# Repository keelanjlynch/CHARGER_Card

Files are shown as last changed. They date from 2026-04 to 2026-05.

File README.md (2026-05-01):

# CHARGER Card

## A compact, interactable business card created for The Univeristy of Alabama in Huntsville Electrical and Computer Engineering Department.

This project was created by Aadam Saafi, Austin Nash, John D'Alessandro, and Keelan Lynch. It utilizes a TFT LCD display, capacative touch buttons, USB interface for flashing/power, and an ESP32-S3-WROOM1.
The code for the project was written in Arduino IDE and the PCB design/layout was created using KiCad. Some of the features of the board in its current state include:

* Three educational activities relating to ECE disciplines included below:
* A Cyber Security activity of brute force byte decryption (similar to mastermind or wordle)
* An Electrical Engineering connect-the-dots activity where user connect electrical components to create an electrical connection
* A Computer Engineering activity where user adjusts inputs and logic gates to get the desired output
* Capacative touch calibration
* Menu selection
* Bitmap rendering

Some additions that could be made using the capabilities of the ESP32-S3:
* Bluetooth utilization
* Wi-Fi utilization
* Artifical Intelligence
* Additional games
* Resume display
* Web browser
* Animated display
* Etc.

## Demo Videos

https://www.youtube.com/watch?v=7o9A-FuoEWo

## How to install this project

1. Clone this project
2. Install Arduino IDE - https://www.arduino.cc/en/software/
3. Install KiCad - https://www.kicad.org/download/

## Opening this project in KiCad (we recommend using V2 of the design)

1. Open Buisness_Card_PCB.kicad_pro in KiCad

## Opening this project in Ardunio

1. Open ChargerCardSoftware.ino in Arduino IDE
2. In Board Manager, install esp32 by Espressif Systems
3. In Library Manager, install "Adafruit GFX Library" and "Adafruit ST7735 and ST7789 Library"
4. Ensure that the CHARGER Card is plugged into your computer via USB
5. From the top menu: Tools > Board: > esp32 > ESP32S3 Dev Module
6. Select the port that the board is currently connected to
7. Once set up, you can upload any changes made in code
8. If this is your first time connecting the board: Hold down the boot switch (lower push button), press and release the reset switch (upper push button), release boot switch. This will put the board into boot mode.

# Altering the code

It will be easiest if you edit this code within an installed verion of the Arduino IDE. The ChargerCardSoftware.ino file is where all code for the project currently resides. 
The bitmaps.h file has all the bitmaps used by the primary ino file. The code is seperate into the following sections: framework drawing functions, cyber activity, ee activity, cpe activity, and framework functions. Global variables can be found at the top of each section (i.e globals used by the cyber activity are found at the top of the cyber activity section).

The setup() and loop() functions are the core of any Arduino code and are located at the very bottom of ChargerCardSoftware.ino. Additional functions and their descriptions are listed below:

* calibrateTouch() - called in setup, establishes a baseline for the capacative touch inputs
* updateTouchReadings() - called in loop to get a current reading from the touch inputs
* touchTest(int i) - compares the given touch point i with the established baseline
* displayLogo() - called to display full sized UAH logo
* drawGithub() - displays bitmap of QR code to this github
* drawFaculty(int f) - called to display image and description for the given UAH ECE faculty member f
* drawMenuSelect() - draws/updates the left side of main menu when the cursor is moved
* drawBonusMenuSelect() - draws/updates the left side of bonus menu when the cursor is moved
* drawMainMenu() - draws main menu
* drawBonusMenu() - draws bonus menu
* drawAboutPage() - draws about page
* returnMainMenu() - used to make main menu our current scene
* moveSelectionLeft() and moveSelectionRight() - used by the CS and EE activity to update the cursor left or right
* toggleSelectedBit() - used by CS activity to toggle the bit highlighted by the cursor
* submitGuess() - used by CS activity when the user presses A
* drawUI() - used by CS activity to draw graphical user interface
* drawTopBar() - component of the CS activity gui
* drawCurrentGuess() - component of the CS activity gui
* drawPreviousGuesses() - component of the CS activity gui
* drawHintBar() - component of the CS activity gui
* drawStats() - component of the CS activity gui
* drawKeyboard() - component of the CS activity gui
* uint8_t countCorrectBits(uint8_t guess, uint8_t target) - CS activity function for counting how many bits are correct
* showVictory() - CS activity function to draw victory message
* showDefeat() - CS activity function to draw game over message
* String getBinaryString(uint8_t num) - string conversion in CS activity
* String getHexString(uint8_t num) - string conversion in CS activity
* newCyberGame() - called when CS activity begins or is reset
* selectCurrentNode() - EE activity function called when user presses A
* initLevel(int level) - EE activity function for level initialization
* setupLevelX() - X is a number, EE activity functions used to initialize each level
* handleNodeTouch(int nodeId) - EE activity function that handles logic for touch on current node
* checkCircuitComplete() - EE activity function that checks if circuit is complete
* drawConnection(int node1, int node2, uint16_t color, int offset) - EE activity function to draw wire connections
* drawComponentSymbol(int x, int y, ComponentType type, bool active) - EE activity function for drawing components
* drawCircuit() - top level EE activity function called when drawing the circuit
* drawNodeLabel(int nodeIndex, uint16_t textColor) - EE activity function that draws a label for each component
* drawControls() - EE activity GUI showing controls
* showError(const char* message) - EE activity error message
* showSuccess() - EE activity level win message
* showGameComplete() - congratulations message shown at the end of EE activity
* resetLevel() - EE activity function to reset current level
* checkVal(int i) - CPE activity recursive function used to test logical output from edited diagram
* drawCursor() - CPE activity function used to draw updated cursor position
* drawWire(int x0, int y0, int i) - CPE activity function to draw wire between current node pos (x0, y0) and other node i
* drawLogic(int i) - CPE activity function to draw/update an input component
* drawNot(int i) - CPE activity function to draw NOT gate
* drawAnd(int i) - CPE activity function to draw AND gate
* drawOr(int i) - CPE activity function to draw OR gate
* drawSwitch(int i) - CPE activity function to draw/update a switch
* drawLED(int i) - CPE activity function to draw output component
* drawComponent(int i) - top level CPE activity function for drawing logic components
* drawWin() - CPE activity function to draw level complete message
* drawCPELevel() - CPE activity function to draw current level
* componentInteract(int i) - CPE activity function that handles if user presses A on component
* startCPELevel(int l) - initializes current CPE level l
* updateCPE() - CPE activity function to refresh screen when an edit was made
* startCPE() - called to begin the CPE activity
* cpeInputHandling(int t) - CPE activity function to handle all acceptable touch button inputs
* enterScene(int s) - used in main menu to switch scene and initialize new scene
* enterBonusScene(int s) - used in main menu to enter bonus menu
* update_mm(int d) - update main menu
* update_bm(int d) - update bonus menu
* update_faculty(int f) - update faculty page
* update_about(int a) - update about page

## Adding Custom Bitmaps

Custom bitmaps can be created from any image and drawn very easily using the Adafruit GFX library. The steps for converting and displaying the image of your choice will be listed below:

1. download your desired image (.png or .jpeg would be best)
2. go to https://javl.github.io/image2cpp/
3. select your file
4. alter canvas size (max size is 320x170 for this device)
5. scale to fit or scale to fill
6. adjust brightness/alpha threshold to get your desired image
7. ensure that code output format is set to Arduino Code, single bitmap
8. change the name of the array to something simple
9. copy and paste array into bitmaps.h file
10. tft.drawBitmap([x_pos],[y_pos],[array name],[width],[height],[color])

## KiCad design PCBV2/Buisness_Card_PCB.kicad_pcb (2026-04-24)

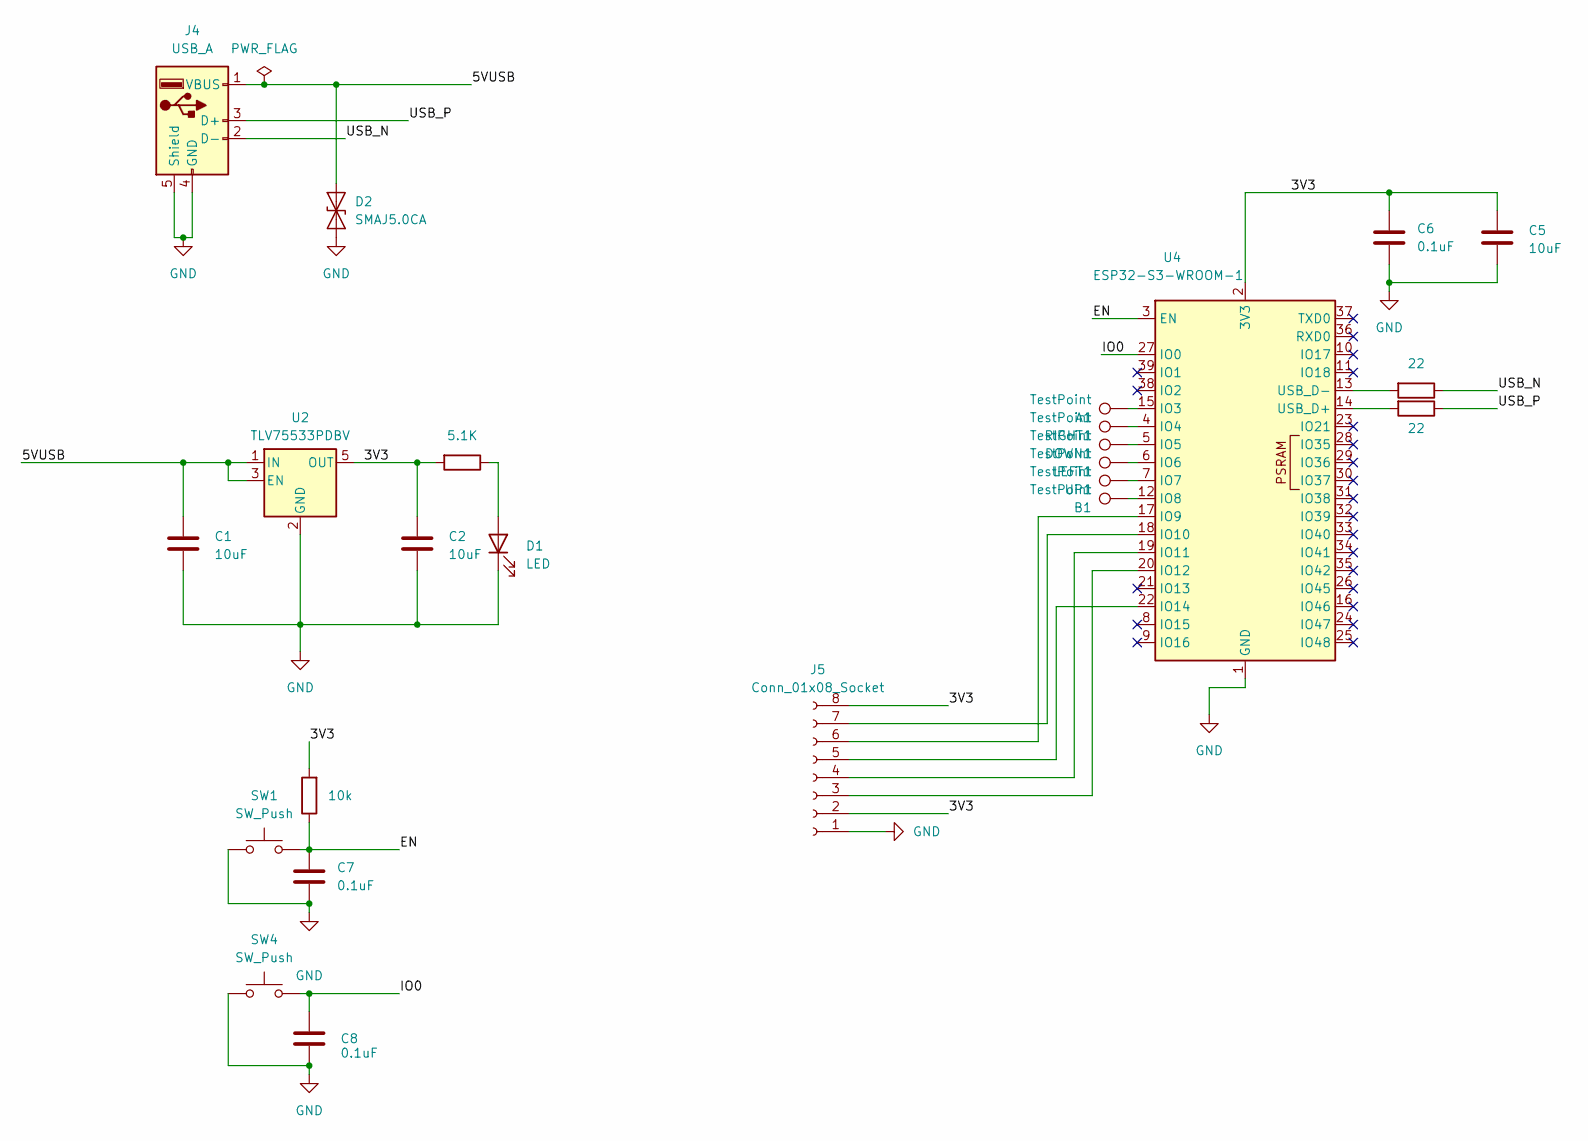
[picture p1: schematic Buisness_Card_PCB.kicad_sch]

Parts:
A1: TestPoint; TouchPad_8mm
B1: TestPoint; TouchPad_8mm
C1, C2, C5: 10uF; C_0201_0603Metric
C6, C7, C8: 0.1uF; C_0201_0603Metric
D1: LED; LED_0201_0603Metric
D2: SMAJ5.0CA; D_SMA
DOWN1: TestPoint; TouchPad_8mm
J4: USB_A; USB_A_PCB_Edge_receptacle
J5: Conn_01x08_Socket; PinHeader_1x08_P2.54mm_Vertical
LEFT1: TestPoint; TouchPad_8mm
R3: 5.1K; R_0201_0603Metric
R4, R6: 22; R_0201_0603Metric
R5: 10k; R_0201_0603Metric
RIGHT1: TestPoint; TouchPad_8mm
SW1, SW4: SW_Push; SW_SPST_TL3305A
U2: TLV75533PDBV; SOT-23-5
U4: ESP32-S3-WROOM-1
UP1: TestPoint; TouchPad_8mm

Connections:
/3V3: C2.2, C5.2, C6.2, J5.2, J5.8, R3.2, R5.2, U2.5 (OUT), U4.2 (3V3)
/5VUSB: C1.2, D2.2 (A2), J4.1 (VBUS), U2.1 (IN), U2.3 (EN)
/EN: C7.2, R5.1, SW1.2, U4.3 (EN)
/IO0: C8.2, SW4.2, U4.27 (IO0)
/USB_N: J4.2 (D-), R4.1
/USB_P: J4.3 (D+), R6.1
GND: C1.1, C2.1, C5.1, C6.1, C7.1, C8.1, D1.1 (K), D2.1 (A1), J4.4 (GND), J4.5 (Shield), J5.1, SW1.1, SW4.1, U2.2 (GND), U4.1 (GND), U4.40 (GND), U4.41 (GND)
unnamed: D1.2 (A), R3.1
unnamed: J5.3, U4.20 (IO12)
unnamed: J5.4, U4.19 (IO11)
unnamed: J5.5, U4.22 (IO14)
unnamed: J5.6, U4.17 (IO9)
unnamed: J5.7, U4.18 (IO10)
unnamed: A1.1, U4.15 (IO3)
unnamed: RIGHT1.1, U4.4 (IO4)
unnamed: DOWN1.1, U4.5 (IO5)
unnamed: LEFT1.1, U4.6 (IO6)
unnamed: U4.7 (IO7), UP1.1
unnamed: B1.1, U4.12 (IO8)
unnamed: R6.2, U4.14 (USB_D+)
unnamed: R4.2, U4.13 (USB_D-)

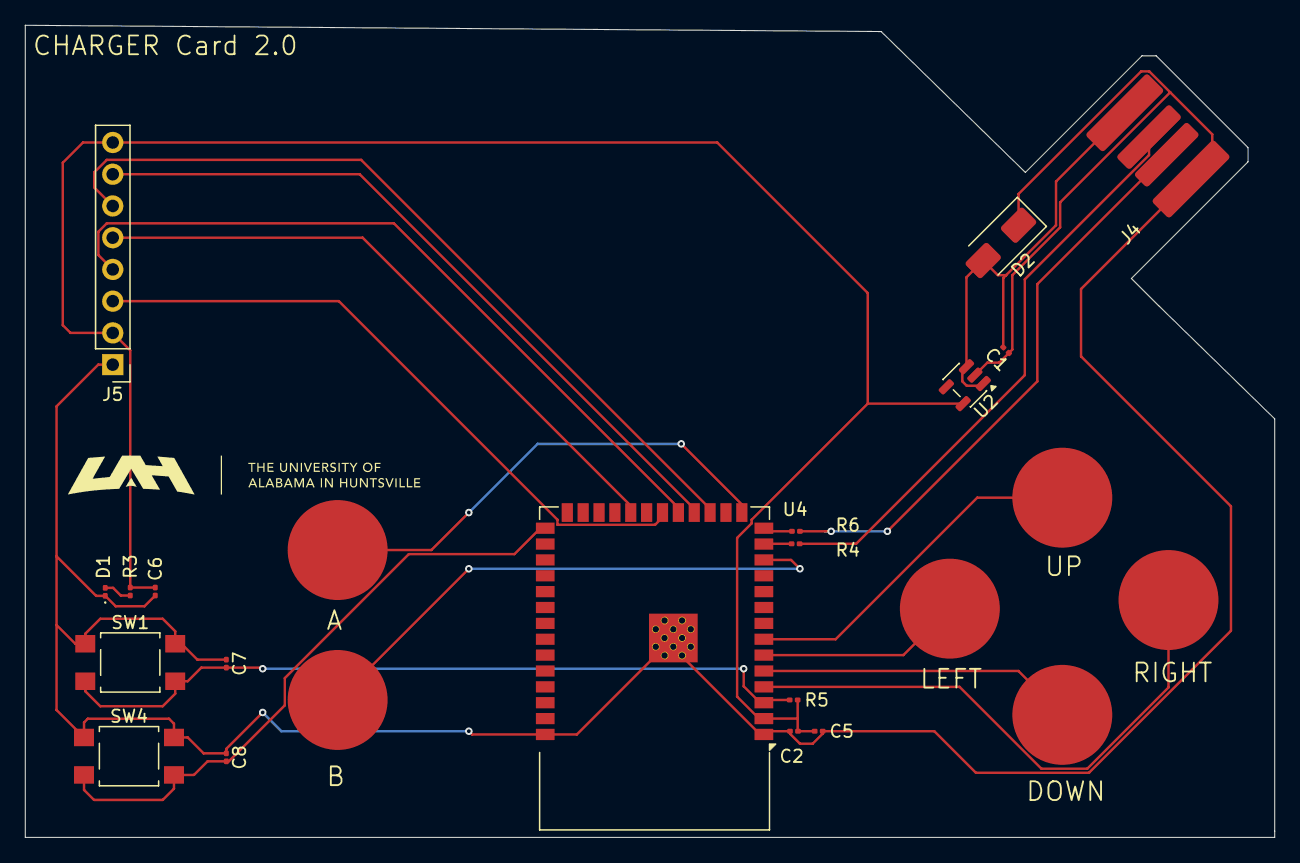
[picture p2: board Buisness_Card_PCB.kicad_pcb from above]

Board: 2 copper layers, 100.0 x 65.0 mm, 24 parts (0 on the bottom side), 21 nets.

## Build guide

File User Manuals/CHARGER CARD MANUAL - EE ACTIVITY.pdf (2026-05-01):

CHARGER CARD MANUAL - EE ACTIVITY

CONTROLS:
- LEFT/RIGHT to move between nodes
- A to select node as next connection
- DOWN to undo
- UP for hint
- B to return to main menu

GAMEPLAY:
- User must connect nodes together to create an electrical connection
- User starts at node S (for start) and ends at node EE (for end)
- Proper connections will show up as a green wire
- Improper connections will result in an error message followed by level reset

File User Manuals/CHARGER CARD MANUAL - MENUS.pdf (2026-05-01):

CHARGER CARD MANUAL - MENUS

CONTROLS:
- UP/DOWN to move between menu options
- A to select a menu option and switch scenes

MENU OPTIONS:
- How To
- Cyber Challenge
- EE Circuit Connect
- CPE Logic Puzzle
- Bonus
- About

LIST OF SCENES

How To:
- Empty at the moment

Cyber Challenge:
- The cyber security activity

EE Circuit Connect:
- The electrical engineering activity

CPE Logic Puzzle:
- The computer engineering activity

Bonus:
- The bonus menu
- The bonus menu has the following options:
- ECE Faculty
- Github
- Return

About:
- The about page
- Displays information about the project
- UP/DOWN to scroll up and down the about page
- B to return to main menu

ECE Faculty:
- The faculty page
- Displays images and descriptions of ECE faculty members
- LEFT/RIGHT to move through ECE faculty members

- B to return to main menu

Github:
- Displays QR code link to project github
- B to return to main menu

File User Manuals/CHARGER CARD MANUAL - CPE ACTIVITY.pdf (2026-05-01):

CHARGER CARD MANUAL - CPE ACTIVITY

CONTROLS:
- UP/DOWN/LEFT/RIGHT to move the cursor (drawn as a square) anywhere on screen
- A to toggle component that the cursor is on (only inputs and switches are interactable)
- B to return to main menu

GAMEPLAY:
- The goal of the player is to get the output to be logical high.
- The player can achieve this by altering input(s) until the proper output is achieved.
- In between the input(s) and the output will be logic gates.
- The player must understand or learn how these gates operate to know which inputs will create the correct output.

LOGIC GATES:

- NOT GATE:
- 1 input
- 1 output
- Outputs the NOT of the input
- Symbol:
- Truth Table:
Input | Output
1 | 0
0 | 1
- AND GATE:
- 2 inputs
- 1 output
- Outputs the AND of the two inputs
- Symbol:

- Truth Table:
Input 1 | Input 2 | Outpu t
0 | 0 | 0
0 | 1 | 0
1 | 0 | 0
1 | 1 | 1
- OR GATE:
- 2 inputs
- 1 output
- Outputs the OR of the two inputs
- Symbal:
- Truth Table:
Input 1 | Input 2 | Outpu t
0 | 0 | 0
0 | 1 | 1
1 | 0 | 1
1 | 1 | 1
- SWITCH:
- 1 input
- 1 output
- If open, output is 0
- If closed, output is the input value
- Can be toggled open or closed by the user
- Symbal:
- INPUT:
- 1 output

- Output is the current value of this component
- Can be toggled high or low by the user
- Symbol is either the character 1 or 0
- OUTPUT:
- 1 input
- Displayed as a large circle
- If input is high, will change to a filled green circle

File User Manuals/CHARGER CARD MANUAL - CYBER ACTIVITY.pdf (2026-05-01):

CHARGER CARD MANUAL - CYBER ACTIVITY

CONTROLS:
- LEFT/RIGHT to move between bits
- UP/DOWN to toggle bit
- A to submit attempt
- B to return to main menu

GAMEPLAY:
- User must brute force an 8 bit encrypted message
- User makes their guess by toggling bits and then submitting their attempt
- The section called “Guesses” displays previous guesses and how many bits out of 8 you had correct
- The user has five tries to submit the proper encrypted byte
- If user is unsuccessful, the game displays “ACCESS DENIED” and the game resets with a new encryption
- If user is successful, the game displays “ACCESS GRANTED” and the user can try a new encryption

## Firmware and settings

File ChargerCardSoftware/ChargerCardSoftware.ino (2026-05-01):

#include <Adafruit_GFX.h>
#include <Adafruit_ST7789.h>
#include <SPI.h>

#include "bitmaps.h"

#define TFT_CS    10
#define TFT_DC     9
#define TFT_RST   14
#define TFT_SCLK  12
#define TFT_MOSI  11

SPIClass mySPI(FSPI);
Adafruit_ST7789 tft = Adafruit_ST7789(&mySPI, TFT_CS, TFT_DC, TFT_RST);

// Touch pins
#define PIN_A      3
#define PIN_B      8
#define PIN_UP     7
#define PIN_DOWN   5
#define PIN_LEFT   6
#define PIN_RIGHT  4

struct TouchButton {
  const char* label;
  int pin;
  int baseline;
  int raw;
  int diff;
  int threshold;
};

TouchButton buttons[] = {
  {"A",     PIN_A,     0, 0, 0, 18},
  {"B",     PIN_B,     0, 0, 0, 18},
  {"UP",    PIN_UP,    0, 0, 0, 18},
  {"DOWN",  PIN_DOWN,  0, 0, 0, 18},
  {"LEFT",  PIN_LEFT,  0, 0, 0, 18},
  {"RIGHT", PIN_RIGHT, 0, 0, 0, 18},
};

const int NUM_BUTTONS = sizeof(buttons) / sizeof(buttons[0]);
int main_selection = 0; //for current cursor position in main menu
int bonus_selection = 0; //for current cursor position in bonus menu
const int BONUS_MAX = 2; //change this constant if you add more options for the bonus menu
int faculty = 0; //numbered 0-20 for all ECE faculty
int scene = 0; //keeps track of current "scene"
              //0 for main menu
              //1 for How To
              //2 for Cyber
              //3 for EE
              //4 for CPE
              //5 for Bonus
              //6 for About
              //7 for ECE Faculty page
              //8 for QR code page

void calibrateTouch() {
  for (int i = 0; i < NUM_BUTTONS; i++) {
    long sum = 0;
    for (int j = 0; j < 40; j++) {
      sum += touchRead(buttons[i].pin);
      delay(10);
    }
    buttons[i].baseline = sum / 40;
  }
}

void updateTouchReadings() {
  for (int i = 0; i < NUM_BUTTONS; i++) {
    buttons[i].raw = touchRead(buttons[i].pin);
    buttons[i].diff = buttons[i].baseline - buttons[i].raw;

    if (buttons[i].diff < 0) {
      buttons[i].diff = 0;
    }
  }
}

bool touchTest(int i) {
  return buttons[i].diff < buttons[i].threshold;
}

void displayLogo() {
  tft.drawBitmap(0,0,uah_logo,320,170,ST77XX_WHITE);
}

void drawGithub() {
  tft.fillScreen(ST77XX_BLACK);
  tft.drawBitmap(85,10,github,150,150,ST77XX_WHITE);
}

void drawFaculty(int f) {
  tft.fillScreen(ST77XX_BLACK);
  tft.setTextColor(ST77XX_WHITE, ST77XX_BLACK);
  __uint16_t faceColor = ST77XX_WHITE;
  switch(f) {
    case 0: //Dr. Beal
      tft.drawBitmap(60,0,beal,320,170,faceColor);
      tft.fillRect(0,0,150,170,ST77XX_BLACK);
      tft.setTextSize(2);
      tft.setCursor(10, 20);
      tft.print("Dr. Beal");
      tft.setTextSize(1);
      tft.setCursor(10, 50);
      tft.print("ASSOCIATE PROFESSOR");
      break;
    case 1: //Dr. Bhadani
      tft.drawBitmap(60,0,bhadani,320,170,faceColor);
      tft.fillRect(0,0,150,170,ST77XX_BLACK);
      tft.setTextSize(2);
      tft.setCursor(10, 20);
      tft.print("Dr. Bhadani");
      tft.setTextSize(1);
      tft.setCursor(10, 50);
      tft.print("ASSISTANT PROFESSOR");
      break;
    case 2: //Dr. Blakely
      tft.drawBitmap(60,0,blakely,320,170,faceColor);
      tft.fillRect(0,0,150,170,ST77XX_BLACK);
      tft.setTextSize(2);
      tft.setCursor(10, 20);
      tft.print("Dr. Blakely");
      tft.setTextSize(1);
      tft.setCursor(10, 50);
      tft.print("ASSISTANT PROFESSOR");
      break;
    case 3: //Bowman
      tft.drawBitmap(60,0,bowman,320,170,faceColor);
      tft.fillRect(0,0,150,170,ST77XX_BLACK);
      tft.setTextSize(2);
      tft.setCursor(10, 20);
      tft.print("Ron Bowman");
      tft.setTextSize(1);
      tft.setCursor(10, 50);
      tft.print("SENIOR LECTURER");
      break;
    case 4: //Dr. Boykin
      tft.drawBitmap(60,0,boykin,320,170,faceColor);
      tft.fillRect(0,0,150,170,ST77XX_BLACK);
      tft.setTextSize(2);
      tft.setCursor(10, 20);
      tft.print("Dr. Boykin");
      tft.setTextSize(1);
      tft.setCursor(10, 50);
      tft.print("PROFESSOR");
      break;
    case 5: //Dr. Coe
      tft.drawBitmap(60,0,coe,320,170,faceColor);
      tft.fillRect(0,0,150,170,ST77XX_BLACK);
      tft.setTextSize(2);
      tft.setCursor(10, 20);
      tft.print("Dr. Coe");
      tft.setTextSize(1);
      tft.setCursor(10, 50);
      tft.print("ASSOCIATE PROFESSOR");
      break;
    case 6: //Dr. English
      tft.drawBitmap(60,0,english,320,170,faceColor);
      tft.fillRect(0,0,150,170,ST77XX_BLACK);
      tft.setTextSize(2);
      tft.setCursor(10, 20);
      tft.print("Dr. English");
      tft.setTextSize(1);
      tft.setCursor(10, 50);
      tft.print("ASSOCIATE DEAN OF");
      tft.setCursor(10, 60);
      tft.print("UNDERGRADUATE AFFAIRS,");
      tft.setCursor(10, 70);
      tft.print("ASSOCIATE PROFESSOR");
      break;
    case 7: //Dr. Gaede
      tft.drawBitmap(60,0,gaede,320,170,faceColor);
      tft.fillRect(0,0,150,170,ST77XX_BLACK);
      tft.setTextSize(2);
      tft.setCursor(10, 20);
      tft.print("Dr. Gaede");
      tft.setTextSize(1);
      tft.setCursor(10, 50);
      tft.print("ASSOCIATE PROVOST,");
      tft.setCursor(10, 60);
      tft.print("ASSOCIATE PROFESSOR");
      break;
    case 8: //Gaur
      tft.drawBitmap(60,0,gaur,320,170,faceColor);
      tft.fillRect(0,0,150,170,ST77XX_BLACK);
      tft.setTextSize(2);
      tft.setCursor(10, 20);
      tft.print("Dr. Gaur");
      tft.setTextSize(1);
      tft.setCursor(10, 50);
      tft.print("ASSISTANT PROFESSOR");
      break;
    case 9: //Dr. Guo
      tft.drawBitmap(60,0,guo,320,170,faceColor);
      tft.fillRect(0,0,150,170,ST77XX_BLACK);
      tft.setTextSize(2);
      tft.setCursor(10, 20);
      tft.print("Dr. Guo");
      tft.setTextSize(1);
      tft.setCursor(10, 50);
      tft.print("PROFESSOR");
      break;
    case 10: //Hite
      tft.drawBitmap(60,0,hite,320,170,faceColor);
      tft.fillRect(0,0,150,170,ST77XX_BLACK);
      tft.setTextSize(2);
      tft.setCursor(10, 20);
      tft.print("Dennis Hite");
      tft.setTextSize(1);
      tft.setCursor(10, 50);
      tft.print("SENIOR LECTURER");
      break;
    case 11: //Dr. Joiner
      tft.drawBitmap(60,0,joiner,320,170,faceColor);
      tft.fillRect(0,0,150,170,ST77XX_BLACK);
      tft.setTextSize(2);
      tft.setCursor(10, 20);
      tft.print("Dr. Joiner");
      tft.setTextSize(1);
      tft.setCursor(10, 50);
      tft.print("ASSOCIATE DEPARTMENT CHAIR,");
      tft.setCursor(10, 60);
      tft.print("ASSOCIATE PROFESSOR");
      break;
    case 12: //Mr. Lawrence
      tft.drawBitmap(60,0,jackson_lawrence,320,170,faceColor);
      tft.fillRect(0,0,150,170,ST77XX_BLACK);
      tft.setTextSize(2);
      tft.setCursor(10, 20);
      tft.print("Jackson Lawrence");
      tft.setTextSize(1);
      tft.setCursor(10, 50);
      tft.print("LECTURER");
      break;
    case 13: //Dr. Lindquist
      tft.drawBitmap(60,0,lindquist,320,170,faceColor);
      tft.fillRect(0,0,150,170,ST77XX_BLACK);
      tft.setTextSize(2);
      tft.setCursor(10, 20);
      tft.print("Dr. Lindquist");
      tft.setTextSize(1);
      tft.setCursor(10, 50);
      tft.print("VICE PRESIDENT FOR RESEARCH");
      tft.setCursor(10, 60);
      tft.print("AND ECONOMIC DEVELOPMENT,");
      tft.setCursor(10, 70);
      tft.print("PROFESSOR");
      break;
    case 14: //Dr. Milenkovic
      tft.drawBitmap(60,0,milenkovic,320,170,faceColor);
      tft.fillRect(0,0,150,170,ST77XX_BLACK);
      tft.setTextSize(2);
      tft.setCursor(10, 20);
      tft.print("Dr. Milenkovic");
      tft.setTextSize(1);
      tft.setCursor(10, 50);
      tft.print("DEPARTMENT CHAIR,");
      tft.setCursor(10, 60);
      tft.print("PROFESSOR");
      break;
    case 15: //Dr. Morris
      tft.drawBitmap(60,0,morris,320,170,faceColor);
      tft.fillRect(0,0,150,170,ST77XX_BLACK);
      tft.setTextSize(2);
      tft.setCursor(10, 20);
      tft.print("Dr. Morris");
      tft.setTextSize(1);
      tft.setCursor(10, 50);
      tft.print("DIRECTOR OF CCRE");
      tft.setCursor(10, 70);
      tft.print("EMINENT SCHOLAR OF");
      tft.setCursor(10, 80);
      tft.print("COMPUTER ENGINEERING");
      break;
    case 16: //Dr. Nguyen
      tft.drawBitmap(60,0,nguyen,320,170,faceColor);
      tft.fillRect(0,0,150,170,ST77XX_BLACK);
      tft.setTextSize(2);
      tft.setCursor(10, 20);
      tft.print("Dr. Nguyen");
      tft.setTextSize(1);
      tft.setCursor(10, 50);
      tft.print("ASSISTANT PROFESSOR");
      break;
    case 17: //Dr. Pan
      tft.drawBitmap(60,0,pan,320,170,faceColor);
      tft.fillRect(0,0,150,170,ST77XX_BLACK);
      tft.setTextSize(2);
      tft.setCursor(10, 20);
      tft.print("Dr. Pan");
      tft.setTextSize(1);
      tft.setCursor(10, 50);
      tft.print("ASSOCIATE PROFESSOR");
      break;
    case 18: //Dr. Pour
      tft.drawBitmap(60,0,pour,320,170,faceColor);
      tft.fillRect(0,0,150,170,ST77XX_BLACK);
      tft.setTextSize(2);
      tft.setCursor(10, 20);
      tft.print("Dr. Pour");
      tft.setTextSize(1);
      tft.setCursor(10, 50);
      tft.print("ASSOCIATE PROFESSOR");
      break;
    case 19: //Dr. Sahoo
      tft.drawBitmap(60,0,sahoo,320,170,faceColor);
      tft.fillRect(0,0,150,170,ST77XX_BLACK);
      tft.setTextSize(2);
      tft.setCursor(10, 20);
      tft.print("Dr. Sahoo");
      tft.setTextSize(1);
      tft.setCursor(10, 50);
      tft.print("ASSISTANT PROFESSOR");
      break;
    case 20: //Dr. Wells
      tft.drawBitmap(60,0,wells,320,170,faceColor);
      tft.fillRect(0,0,150,170,ST77XX_BLACK);
      tft.setTextSize(2);
      tft.setCursor(10, 20);
      tft.print("Dr. Wells");
      tft.setTextSize(1);
      tft.setCursor(10, 50);
      tft.print("PROFESSOR");
      break;
    default:
      break;
  }
}

void drawMenuSelect() {
  tft.fillRect(0,0,150,170,ST77XX_BLACK);
  tft.setTextSize(1);
  tft.setTextColor(ST77XX_WHITE);

  tft.drawRect(0,10,130,25,ST77XX_WHITE); //How To
  tft.setCursor(5,20);
  tft.print("How To");

  tft.drawRect(0,35,130,25,ST77XX_WHITE); //Cyber Challenge
  tft.setCursor(5,45);
  tft.print("Cyber Challenge");

  tft.drawRect(0,60,130,25,ST77XX_WHITE); //EE Circuit Maker
  tft.setCursor(5,70);
  tft.print("EE Circuit Connect");

  tft.drawRect(0,85,130,25,ST77XX_WHITE); //CPE Logic Puzzle
  tft.setCursor(5,95);
  tft.print("CPE Logic Puzzle");

  tft.drawRect(0,110,130,25,ST77XX_WHITE); //Bonus
  tft.setCursor(5,120);
  tft.print("Bonus");

  tft.drawRect(0,135,130,25,ST77XX_WHITE); //Touch Test
  tft.setCursor(5,145);
  tft.print("About");
  
  tft.setTextColor(ST77XX_BLACK);

  switch (main_selection) {
    case 0:
      tft.fillRect(0,10,150,25,ST77XX_WHITE); //How To select
      tft.setCursor(10,20);
      tft.print("How To");
      break;
    case 1:
      tft.fillRect(0,35,150,25,ST77XX_WHITE); //Cyber Challenge select
      tft.setCursor(10,45);
      tft.print("Cyber Challenge");
      break;
    case 2:
      tft.fillRect(0,60,150,25,ST77XX_WHITE); //EE Circuit Maker select
      tft.setCursor(10,70);
      tft.print("EE Circuit Connect");
      break;
    case 3:
      tft.fillRect(0,85,150,25,ST77XX_WHITE); //CPE Logic Puzzle select
      tft.setCursor(10,95);
      tft.print("CPE Logic Puzzle");
      break;
    case 4:
      tft.fillRect(0,110,150,25,ST77XX_WHITE); //Bonus
      tft.setCursor(10,120);
      tft.print("Bonus");
      break;
    case 5:
      tft.fillRect(0,135,150,25,ST77XX_WHITE); //About
      tft.setCursor(10,145);
      tft.print("About");
      break;
    default:
      break;
  }

}

void drawBonusMenuSelect() {
  tft.fillRect(0,0,150,170,ST77XX_BLACK);
  tft.setTextSize(1);
  tft.setTextColor(ST77XX_WHITE);

  tft.drawRect(0,10,130,25,ST77XX_WHITE); //ECE Faculty
  tft.setCursor(5,20);
  tft.print("ECE Faculty");

  tft.drawRect(0,35,130,25,ST77XX_WHITE); //Github
  tft.setCursor(5,45);
  tft.print("Github");

  tft.drawRect(0,60,130,25,ST77XX_WHITE); //Return
  tft.setCursor(5,70);
  tft.print("Return");

  // bonus menu can be expanded further, just make sure that the bonus selection variable can go up to the correct amount (a global constant called BONUS_MAX)
  // tft.drawRect(0,85,130,25,ST77XX_WHITE); //menu option 4
  // tft.setCursor(5,95);
  // tft.print("");

  // tft.drawRect(0,110,130,25,ST77XX_WHITE); //menu option 5
  // tft.setCursor(5,120);
  // tft.print("");

  // tft.drawRect(0,135,130,25,ST77XX_WHITE); //menu option 6
  // tft.setCursor(5,145);
  // tft.print("");
  
  tft.setTextColor(ST77XX_BLACK);

  switch (bonus_selection) {
    case 0:
      tft.fillRect(0,10,150,25,ST77XX_WHITE); //Faculty select
      tft.setCursor(10,20);
      tft.print("ECE Faculty");
      break;
    case 1:
      tft.fillRect(0,35,150,25,ST77XX_WHITE); //Github select
      tft.setCursor(10,45);
      tft.print("Github");
      break;
    case 2:
      tft.fillRect(0,60,150,25,ST77XX_WHITE); //Return select
      tft.setCursor(10,70);
      tft.print("Return");
      break;
    // case 3:
    //   tft.fillRect(0,85,150,25,ST77XX_WHITE); //option 4
    //   tft.setCursor(10,95);
    //   tft.print("");
    //   break;
    // case 4:
    //   tft.fillRect(0,110,150,25,ST77XX_WHITE); //option 5
    //   tft.setCursor(10,120);
    //   tft.print("");
    //   break;
    // case 5:
    //   tft.fillRect(0,135,150,25,ST77XX_WHITE); //option 6
    //   tft.setCursor(10,145);
    //   tft.print("");
    //   break;
    default:
      break;
  }

}


void drawMainMenu() {
  tft.fillScreen(ST77XX_BLACK);
  tft.drawBitmap(180,20,uah_logo_small,100,32,ST77XX_BLUE);
  tft.setCursor(177,60);
  tft.setTextSize(2);
  tft.setTextColor(ST77XX_WHITE);
  tft.print("Main Menu");

  tft.setCursor(160,140);
  tft.setTextSize(1);
  tft.print("Up/Down to navigate.");

  tft.setCursor(160,150);
  tft.print("A to select.");
  
  drawMenuSelect();
}

void drawBonusMenu() {
  tft.fillScreen(ST77XX_BLACK);
  tft.drawBitmap(180,20,uah_logo_small,100,32,ST77XX_BLUE);
  tft.setCursor(165,60);
  tft.setTextSize(2);
  tft.setTextColor(ST77XX_WHITE);
  tft.print("Bonus Menu");

  tft.setCursor(160,140);
  tft.setTextSize(1);
  tft.print("Up/Down to navigate.");

  tft.setCursor(160,150);
  tft.print("A to select.");
  
  drawBonusMenuSelect();
}

int about_Y = 0; //global variable to track the Y position of the about page

void drawAboutPage() {
  tft.fillScreen(ST77XX_BLACK);
  tft.drawBitmap(110,about_Y + 20,uah_logo_small,100,32,ST77XX_BLUE);
  tft.setTextSize(1);
  tft.setTextColor(ST77XX_WHITE);

  tft.setCursor(100,about_Y + 60);
  tft.print("This is CHARGER Card.");
  tft.setCursor(20,about_Y + 80);
  tft.print("A hands on experience to promote the");
  tft.setCursor(20,about_Y + 90);
  tft.print("Electrical and Computer Engineering department");
  tft.setCursor(20,about_Y + 100);
  tft.print("at the University of Alabama in Huntsville.");

  tft.setCursor(120,about_Y + 140);
  tft.print("Developed By");
  tft.setCursor(60,about_Y + 160);
  tft.print("Aadam Saafi");
  tft.setCursor(180,about_Y + 160);
  tft.print("Austin Nash");
  tft.setCursor(40,about_Y + 180);
  tft.print("John D'Alessandro");
  tft.setCursor(180,about_Y + 180);
  tft.print("Keelan Lynch");

  tft.setCursor(100,about_Y + 220);
  tft.print("With Assistance From");
  tft.setCursor(115,about_Y + 240);
  tft.print("Dr. Emil Jovanov");
  tft.setCursor(110,about_Y + 260);
  tft.print("Dr. Buren E. Wells");
  tft.setCursor(115,about_Y + 280);
  tft.print("Dr. Brian Smith");
  tft.setCursor(115,about_Y + 300);
  tft.print("Dr. Aubrey Beal");
  tft.setCursor(120,about_Y + 320);
  tft.print("William Lochte");

  tft.setCursor(40,about_Y + 360);
  tft.print("Requested on behalf of the ECE Department");
  tft.setCursor(120,about_Y + 370);
  tft.print("by Dr. David Coe");

  tft.setCursor(60,about_Y + 410);
  tft.print("Project Sponsored by Dr. David Coe");

  tft.setCursor(60,about_Y + 480);
  tft.print("Univeristy of Alabama in Huntsville");
  tft.setCursor(100,about_Y + 490);
  tft.print("Computer Engineering");
  tft.setCursor(110,about_Y + 500);
  tft.print("Senior Design 2026");
}

void returnMainMenu() {
  scene = 0;
  drawMainMenu();
}

/*********************CYBER CHALLENGE*********************/
// =====================================================
// Game settings
// =====================================================
#define CODE_BITS      8
#define MAX_GUESSES    5

// =====================================================
// Custom colors
// =====================================================
#define COLOR_CORRECT    0x07E0
#define COLOR_WRONG      0x7800
#define COLOR_BG         0x0841
#define COLOR_BUTTON     0x4208
#define COLOR_BUTTON_ON  0x07FF
#define COLOR_PANEL      0x0000
#define COLOR_TEXT       0xFFFF
#define COLOR_INFO       0xFFE0
#define COLOR_ACCENT     0x07FF
#define COLOR_CURSOR     0xF81F

// =====================================================
// Game state
// =====================================================
uint8_t targetNumber = 0;                   // 0-255
uint8_t currentGuess = 0;
uint8_t guesses[MAX_GUESSES];
uint8_t guessScores[MAX_GUESSES];           // number of correct bits per guess
uint8_t guessCount = 0;
uint8_t selectedBit = 7;                    // start on MSB

bool gameWon = false;
bool gameLost = false;

// =====================================================
// Statistics
// =====================================================
uint16_t gamesPlayed = 0;
uint16_t gamesWon = 0;
uint16_t currentStreak = 0;
uint16_t bestStreak = 0;

// =====================================================
// Feedback
// =====================================================
String lastHint = "";

void moveSelectionLeft() {
  if (selectedBit < 7) {
    selectedBit++;
    drawCurrentGuess();
  }
}

void moveSelectionRight() {
  if (selectedBit > 0) {
    selectedBit--;
    drawCurrentGuess();
  }
}

void toggleSelectedBit() {
  currentGuess ^= (1 << selectedBit);
  drawCurrentGuess();
}

void submitGuess() {
  if (gameWon || gameLost) return;
  if (guessCount >= MAX_GUESSES) return;

  guesses[guessCount] = currentGuess;
  guessScores[guessCount] = countCorrectBits(currentGuess, targetNumber);
  guessCount++;

  lastHint = String(guessScores[guessCount - 1]) + " bits correct";

  Serial.print("Guess #");
  Serial.print(guessCount);
  Serial.print(": ");
  Serial.print(getBinaryString(currentGuess));
  Serial.print(" | Correct bits: ");
  Serial.println(guessScores[guessCount - 1]);

  if (currentGuess == targetNumber) {
    gameWon = true;
    gamesPlayed++;
    gamesWon++;
    currentStreak++;
    if (currentStreak > bestStreak) bestStreak = currentStreak;

    drawPreviousGuesses();
    drawHintBar();
    drawStats();
    showVictory();
    return;
  }

  if (guessCount >= MAX_GUESSES) {
    gameLost = true;
    gamesPlayed++;
    currentStreak = 0;

    drawPreviousGuesses();
    drawHintBar();
    drawStats();
    showDefeat();
    return;
  }

  drawPreviousGuesses();
  drawHintBar();
  drawStats();
}
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
void loop() {
  updateTouchReadings();

  switch (scene) {
    case 0: //main menu
      if(touchTest(2)){update_mm(0);} //UP
      if(touchTest(3)){update_mm(1);} //DOWN
      if(touchTest(0)){update_mm(2);} //A
      break;
    case 1: //How to
      break;
    case 2: //Cyber
      if (!gameWon && !gameLost) {
        if (touchTest(4)) moveSelectionLeft();   // LEFT
        if (touchTest(5)) moveSelectionRight();  // RIGHT
        if (touchTest(2)) toggleSelectedBit();   // UP
        if (touchTest(3)) toggleSelectedBit();   // DOWN
        if (touchTest(0)) submitGuess();         // A
        if (touchTest(1)) returnMainMenu();       // B
      } else {
        if (touchTest(0)) {
          newCyberGame();
        }
        if (touchTest(1)) {
          returnMainMenu();
        }
      }
      break;
    case 3: //EE
      if (gameComplete) {
        if (touchTest(0)) {   // A = next level
          currentLevel++;
          if (currentLevel >= totalLevels) {
            currentLevel = 0;
            showGameComplete();
            delay(1500);
          }
          initLevel(currentLevel);
          drawCircuit();
        }
        else if (touchTest(1)) {   // B = restart
          currentLevel = 0;
          initLevel(currentLevel);
          drawCircuit();
        }
      }

      if (touchTest(4)) {          // LEFT
        eeMoveSelectionLeft();
      }
      else if (touchTest(5)) {     // RIGHT
        eeMoveSelectionRight();
      }
      else if (touchTest(0)) {     // A
        selectCurrentNode();
      }
      else if (touchTest(1)) {     // B
        returnMainMenu();
      }
      else if (touchTest(3)) {     // DOWN
        undoMove();
      }
      else if (touchTest(2)) {     // UP
        showHintOverlay = !showHintOverlay;
        drawCircuit();
      }
      break;
    case 4: //CPE
      if (won) {
        if (touchTest(0)){startCPELevel(currentCpeLevel + 1);}  // A
      }
      else {
        if (touchTest(0)){cpeInputHandling(0);}  // A
        if (touchTest(1)){returnMainMenu();}  // B
        if (touchTest(2)){cpeInputHandling(2);}  // UP
        if (touchTest(3)){cpeInputHandling(3);}  // DOWN
        if (touchTest(4)){cpeInputHandling(4);}  // LEFT
        if (touchTest(5)){cpeInputHandling(5);}  // RIGHT
      }
      break;
    case 5: //Bonus
      if(touchTest(2)){update_bm(0);} //UP
      if(touchTest(3)){update_bm(1);} //DOWN
      if(touchTest(0)){update_bm(2);} //A
      break;
    case 6: //About
      if(touchTest(2)){update_about(0);} //UP
      if(touchTest(3)){update_about(1);} //DOWN
      if(touchTest(1)){returnMainMenu();}//B
      break;
    case 7: //Faculty and staff
      if (touchTest(4)){update_faculty(0);}  // left
      if (touchTest(5)){update_faculty(1);}  // right
      if(touchTest(1)){scene = 5; drawBonusMenu();}//B
      break;
    case 8: //Github QR
      if(touchTest(1)){scene = 5; drawBonusMenu();}//B
      break;
    default:
      break;
  }

  delay(60);
}

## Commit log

2026-04-24 Established new GitHub
    [Buisness_Card_PCB-B_Cu.gbr, Buisness_Card_PCB-B_Mask.gbr, Buisness_Card_PCB-B_Paste.gbr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]
2026-05-01 Update ChargerCardSoftware.ino
    removed copies of functions
2026-05-01 Update ChargerCardSoftware.ino
    undid changes made to ee activity
2026-05-01 Create CHARGER CARD MANUAL - MENUS.pdf
